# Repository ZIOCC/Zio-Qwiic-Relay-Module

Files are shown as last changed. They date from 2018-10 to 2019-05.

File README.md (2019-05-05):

# Zio Qwiic Relay Module

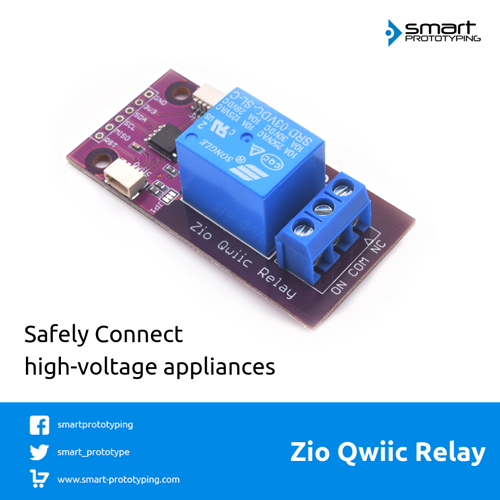
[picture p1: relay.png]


> This product can be available for purchase [here](https://www.smart-prototyping.com/Zio-Qwiic-Relay).

#### Description

Sometimes we need to control high voltage appliances to work with our components. To control that high current, we send an MCU command to a relay module. There are many relay modules out there that can do just that, but what is so great about ours is, it has I2C feature embedded in the module, hence the name ‘Qwiic Relay Module’.

By adding an I2C gateway MCU (ATTINY85-20SU), we have turned this relay module into Qwiic compatible module, no more complications with jumper wire connections, just connect with Qwiic cable!

> Warning: The max. load of this module is not the relay itself, it is the line that connects the pins on the PC. Our module max. allowed current is 4.5A! For your safety, do not connect to devices that are higher than 4.0A.  

#### Specification

* MCU Operation Voltage: 3.3V
* Max. Load for appliances: 4.0A at 125V AC or 250V AC
* Gateway MCU: ATTINY85-20SU
* I2C address: 0x07- 0x78 (Default:0x18)
* Weight: 17.0G
* Dimension: 27.4 x 55.9 x 17.2 (H) mm

#### Links

* [Eagle File and gerber files](https://github.com/ZIOCC/Zio-Qwiic-Relay-Module)
* [Schematic](https://github.com/ZIOCC/Zio-Qwiic-Relay-Module/blob/master/Zio%20Qwiic%20Relay%20Module%20Schematic%20PDF.pdf)
* [Gateway firmware](https://github.com/ZIOCC/Zio-Qwiic-Relay-Module/tree/master/firmware/Qwiic_Relay_Gateway_Firmware)

> This Qwiic version Relay module is referenced from [Sparkfun's Qwiic Relay](https://www.sparkfun.com/products/14712) design and their firmware.

> The gateway MCU is ATTINY85-20SU, check out the datasheet [here](https://www.mouser.com/datasheet/2/268/Atmel-2586-AVR-8-bit-Microcontroller-ATtiny25-ATti-1315542.pdf).

> ###### About Zio
> Zio is a new line of open sourced, compact, and grid layout boards, fully integrated for Arduino and Qwiic ecosystem. Designed ideally for wearables, robotics, small-space limitations or other on the go projects. Check out other awesome Zio products [here](https://www.smart-prototyping.com/Zio).

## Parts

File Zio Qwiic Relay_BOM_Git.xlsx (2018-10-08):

 | BOM quantity |  |  | Zio Qwiic Relay | V 1.0 |  |  |  |  | Harry | 2018.8.31
 | Part Identification |  |  |  |  |  |  |  | Customer Information |  | Quantity
# | Part ID / Reference | Manufacturer | Part / Order Number | Description | Value | Package | THT (y/n) | Pins / Pads | Source/Link/ Datasheet/Note | Source / Target Price | Quantity per BOM
1 | C1 |  |  |  | 100nF ±10% 50V | C0603 | n | 2 |  |  | 1
2 | D1 |  |  |  | RED | LED-0603 | n | 2 |  |  | 1
3 | D2 | MDD | B5817WS-SJ |  | B5817WS-SJ | SOD323 | n | 3 |  |  | 1
4 | J1 | KANGNEX | WJ301V-5.0-3P |  | WJ301V-5.0-3P | 3P-SCREW-5.08 | y | 3 |  |  | 1
5 | J2, J3 |  |  |  | JST-SH-4P-1.0 | JST-SH-4P | n | 6 |  |  | 2
6 | J4 |  | NA |  | 6P-2.54 | 6P-2.54-60/35MIL | y | 6 |  |  | 1
7 | Q1 | ON | MMBT2222ALT1G |  | MMBT2222ALT1G | SOT23 | n | 3 |  |  | 1
8 | R1 |  |  |  | 10R ±1% | R0603 | n | 2 |  |  | 1
9 | R2, R7 |  |  |  | 1k ±1% | R0603 | n | 2 |  |  | 2
10 | R3, R6 |  |  |  | 10k ±1% | R0603 | n | 2 |  |  | 2
11 | R4, R5 |  |  |  | 4.7K ±1% | R0603 | n | 2 |  |  | 2
12 | RELAY1 | 松乐 | SRD-03VDC-SL-C 蓝色 |  | RELAY-5 | RELAY-5 | y | 5 |  |  | 1
13 | U1 | MICROCHIP | ATTINY85-20SU |  | ATTINY85-S | SOIC8_EIAJ_208MIL | n | 8 |  |  | 1

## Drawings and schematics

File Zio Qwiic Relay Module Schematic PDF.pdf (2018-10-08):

MMBT2222ALT1G 100nF ±10% ⁵⁰V | RED | B⁵⁸¹⁷WS⁻SJ ¹⁰R ±1%
1 | 2 | 3 | 4

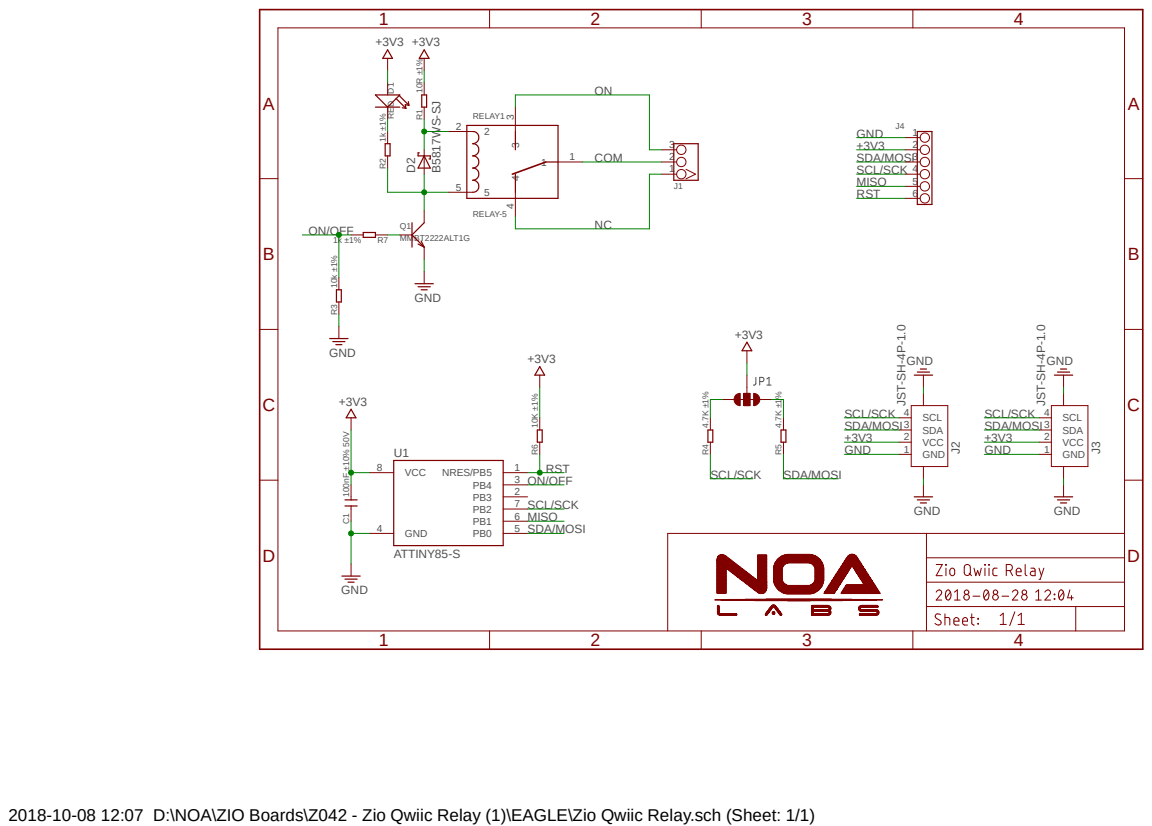
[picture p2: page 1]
ATTINY85-S; GND; GND 4.7K ±1%; RELAY-5; GND ¹⁰k ±1%; 1k ±1% GND; NRES/PB5; 1 VCC 8; GND 4; GND 1; VCC 2; SDA 3; SCL 4; J3 JST⁻SH⁻⁴P⁻¹.0; J2 JST⁻SH⁻⁴P⁻¹.0 R⁴; RELAY1 2; SDA/MOSI; SCL/SCK; ON/OFF; COM; RST; MISO

2018-10-08 12:07 D:\NOA\ZIO Boards\Z042 - Zio Qwiic Relay (1)\EAGLE\Zio Qwiic Relay.sch (Sheet: 1/1)

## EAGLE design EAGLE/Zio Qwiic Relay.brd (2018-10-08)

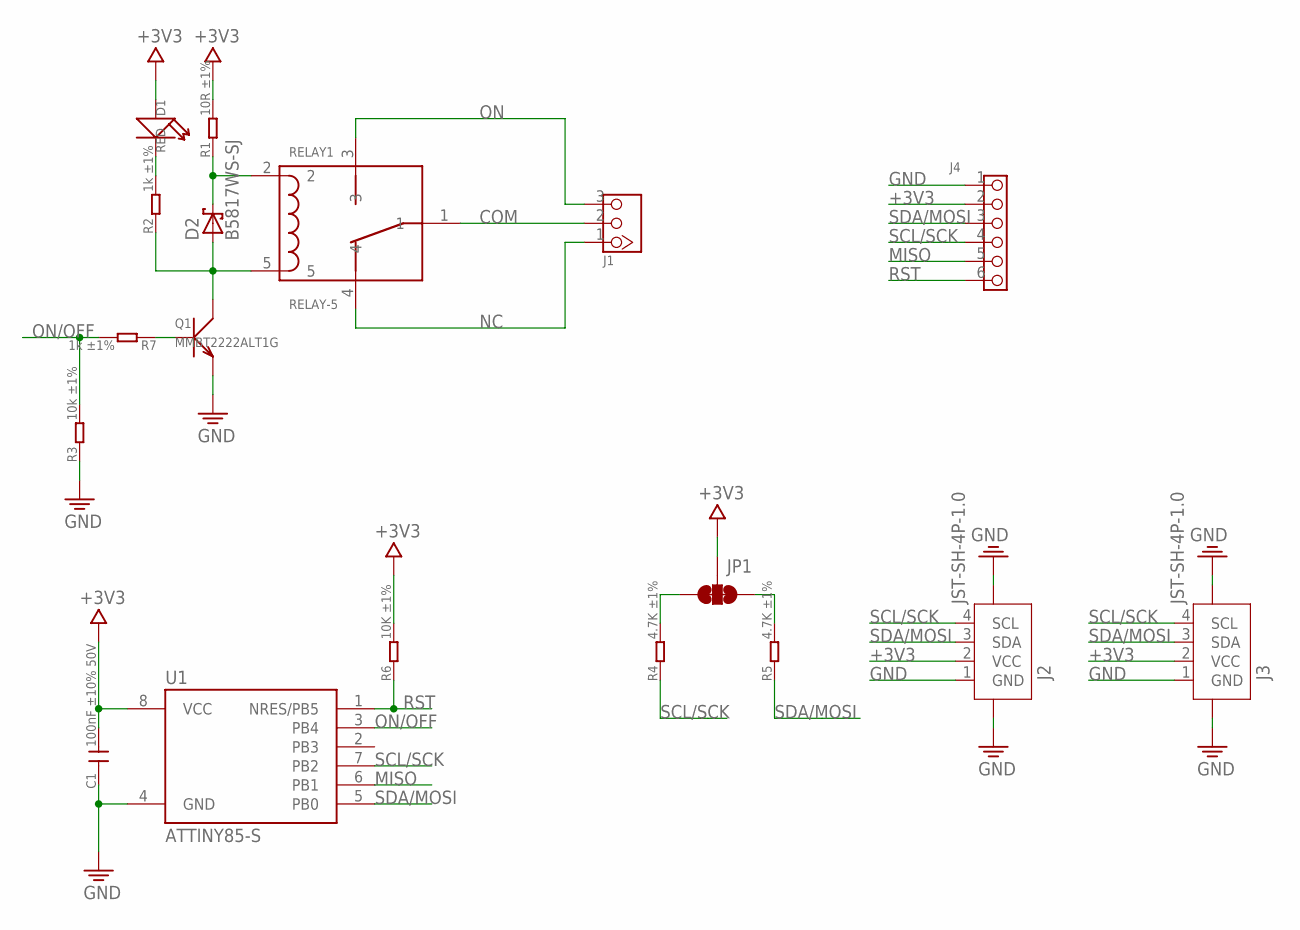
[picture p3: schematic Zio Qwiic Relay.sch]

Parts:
C1: 100nF ±10% 50V; C0603
D1: RED; LED-0603
D2: B5817WS-SJ; SOD323
J1: HEADER-3P; 3P-SCREW-5.08
J2, J3: JST-SH-4P-1.0; JST-SH-4P
J4: HEADER-6P-60/35MIL; 6P-2.54-60/35MIL
JP1: SMT-JUMPER_3_2-NC_TRACE
Q1: MMBT2222ALT1G; SOT23
R1: 10R ±1%; R0603
R2, R7: 1k ±1%; R0603
R3: 10k ±1%; R0603
R4, R5: 4.7K ±1%; R0603
R6: 10K ±1%; R0603
RELAY1: RELAY-5
U1: ATTINY85-S; SOIC8_EIAJ_208MIL

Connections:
+3V3: C1.2, D1.+, J2.2 (VCC), J3.2 (VCC), J4.2, JP1.2, R1.2, R6.2, U1.8 (VCC)
COM: J1.2, RELAY1.1
GND: C1.1, J2.1 (GND), J2.NC1 (5), J2.NC2 (6), J3.1 (GND), J3.NC1 (5), J3.NC2 (6), J4.1, Q1.2 (E), R3.1, U1.4 (GND)
MISO: J4.5, U1.6 (PB1)
unnamed: D2.- (C), R1.1, RELAY1.2
unnamed: Q1.1 (B), R7.1
unnamed: D1.-, R2.2
unnamed: D2.+ (A), Q1.3 (C), R2.1, RELAY1.5
unnamed: JP1.3, R4.2
unnamed: JP1.1, R5.2
NC: J1.1, RELAY1.4
ON: J1.3, RELAY1.3
ON/OFF: R3.2, R7.2, U1.3 (PB4)
RST: J4.6, R6.1, U1.1 (NRES/PB5)
SCL/SCK: J2.4 (SCL), J3.4 (SCL), J4.4, R4.1, U1.7 (PB2)
SDA/MOSI: J2.3 (SDA), J3.3 (SDA), J4.3, R5.1, U1.5 (PB0)

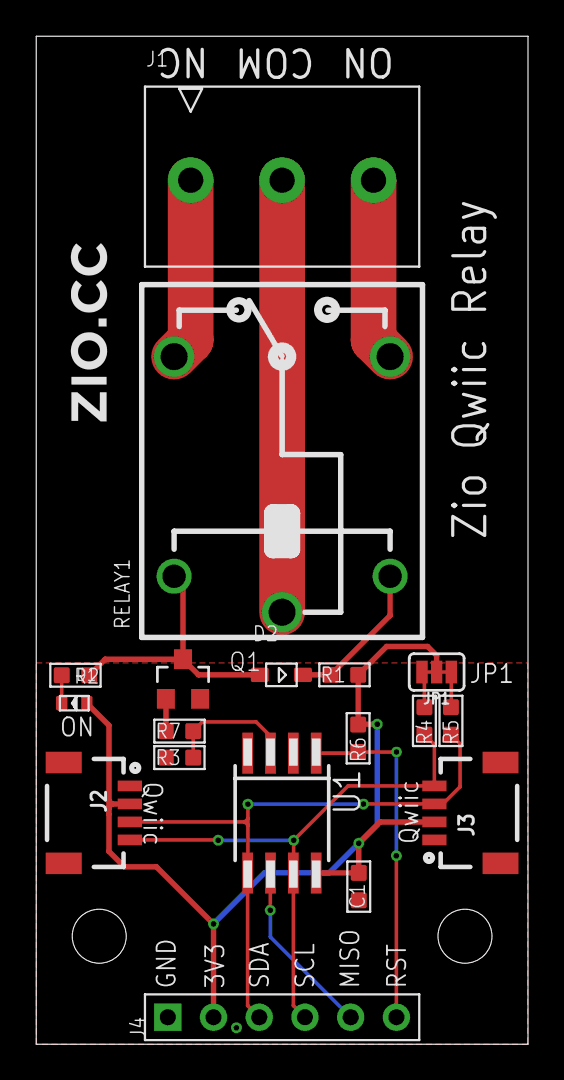
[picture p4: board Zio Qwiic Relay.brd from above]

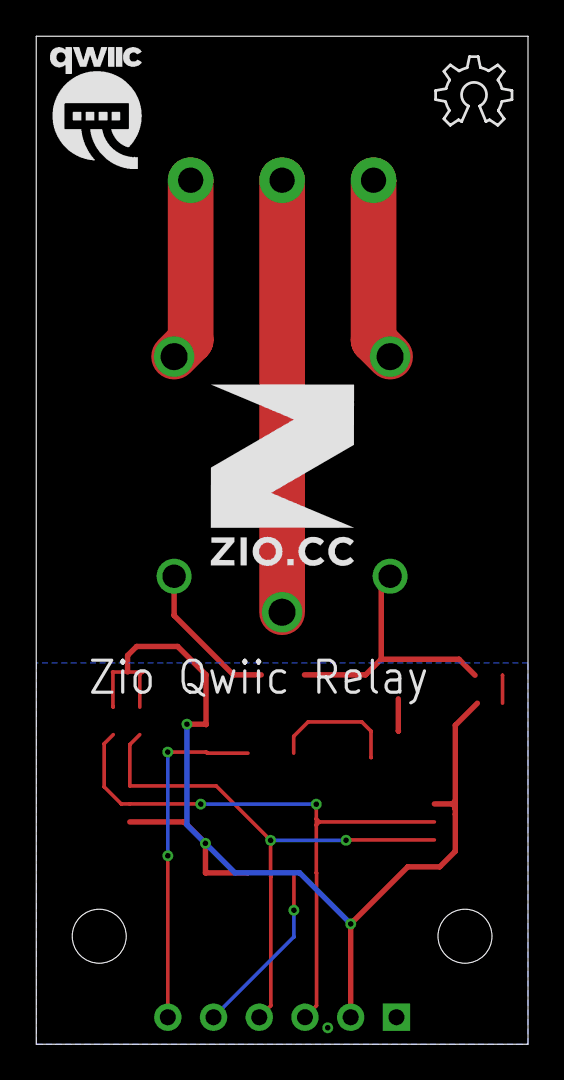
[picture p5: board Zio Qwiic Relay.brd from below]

Board: 2 copper layers, 27.3 x 56.0 mm, 22 parts (3 on the bottom side), 16 nets.

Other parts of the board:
U$3: 10MM
U$6: QWIIC-LOGO-MEDIUM
U$7: OSHW_6X150_NOTEXT
U$9: 2MM

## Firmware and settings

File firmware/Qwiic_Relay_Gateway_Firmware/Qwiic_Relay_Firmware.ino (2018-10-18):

/******************************************************************************
  Qwiic Relay Firmware
  Kevin Kuwata @ SparkX
  March 21, 2018
  https://github.com/sparkfunX/Qwiic_Relay
  Arduino 1.8.5

  This is the firmware on the Qwiic Relay. The default I2C Address is
  0x18;

******************************************************************************/
#include <TinyWire.h> //https://github.com/lucullusTheOnly/TinyWire
#include <EEPROM.h>

#define RELAY_PIN   4
#define SETTING_LOCATION_ADDRESS	1

volatile byte qwiicRelayAddress  =    0x18; //default

#define COMMAND_RELAY_OFF 			0x00
#define COMMAND_RELAY_ON 			0x01
#define COMMAND_CHANGE_ADDRESS 		0x03
#define COMMAND_FIRMWARE_VERSION 	0x04
#define COMMAND_STATUS 				0x05
#define COMMAND_HAS_BEEN_CHECKED 	0x99

const byte firmwareVersionMajor = 1;
const byte firmwareVersionMinor = 0;

volatile byte command = COMMAND_HAS_BEEN_CHECKED;
volatile byte address = COMMAND_HAS_BEEN_CHECKED;


void setup() {
  //Read EEPROM, is it empty (0xFF)? or does it have a value?
  qwiicRelayAddress =  EEPROM.read(SETTING_LOCATION_ADDRESS);
  if (qwiicRelayAddress == 0xFF) {
    //EEPROM has never been written before, use the default address 0x18.
    qwiicRelayAddress = 0x18; //default
  }

  pinMode(RELAY_PIN, OUTPUT);
  digitalWrite(RELAY_PIN, LOW);

  TinyWire.begin(qwiicRelayAddress);
  TinyWire.onReceive(receiveEvent); // register event
  TinyWire.onRequest(onI2CRequest);
}

void loop() {
}

/*========================================================*/
//        ISR
/*========================================================*/

// When the master initiates a command and data to slave
//		ie) the master says 0x01, then sends a 1, means command: 0x01 then the slave listens for the next thing, which is the relay state 1
void receiveEvent(int bytesReceived) {
  byte count = 0;
  while (TinyWire.available() > 0) {
    if (count == 0) {
      command = TinyWire.read();

      if (command == COMMAND_RELAY_ON) {
        digitalWrite(RELAY_PIN, HIGH);
        command = COMMAND_HAS_BEEN_CHECKED;
      }
      else if (command == COMMAND_RELAY_OFF) {
        digitalWrite(RELAY_PIN, LOW);
        command = COMMAND_HAS_BEEN_CHECKED;
      }
    }
    else if (count == 1) {
      if (command == COMMAND_CHANGE_ADDRESS) {
        byte address = TinyWire.read();

        if (address > 0x07 && address < 0x78) {
          //valid address, update and save to EEPROM
          qwiicRelayAddress = address;

          EEPROM.write(SETTING_LOCATION_ADDRESS, qwiicRelayAddress);
          TinyWire.begin(qwiicRelayAddress);
        }
      }
    }
    else {
      TinyWire.read(); //read the data coming in but ignore it.
    }
    count++;
  }
}// end of receive ISR



//When the master requests data from the slave, this
//    ISR is triggered.

void onI2CRequest() {
  //not sure if this will work because the master sends 0x04, then the salve enters the RX event isr
  // then goes to main, sets the flag. then if that happens slower than versionFlag we have a race condition.
  if (command == COMMAND_FIRMWARE_VERSION) {
    //TinyWire.send(firmwareVersion);// tiny wire can't send multiple bytes.
    TinyWire.send(firmwareVersionMajor);
    TinyWire.send(firmwareVersionMinor);

    command = COMMAND_HAS_BEEN_CHECKED;
  }
  else if (command == COMMAND_STATUS) {
    if (digitalRead(RELAY_PIN) == HIGH)
      TinyWire.send(COMMAND_RELAY_ON);
    else
      TinyWire.send(COMMAND_RELAY_OFF);

    command = COMMAND_HAS_BEEN_CHECKED;
  }
}
